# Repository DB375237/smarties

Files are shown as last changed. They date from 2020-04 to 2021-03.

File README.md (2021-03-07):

# Smarties™ Dispenser

Basic Arduino based dispenser. It can be activated via Bluetooth with an HC-05 module.

Dispenser in Action

## How it started
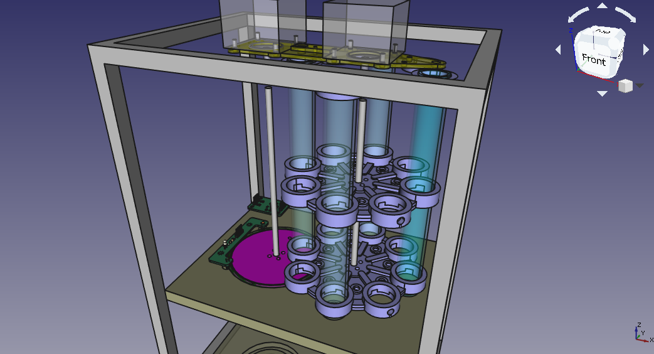
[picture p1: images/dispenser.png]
Rendering of Dispenser


## How it's going
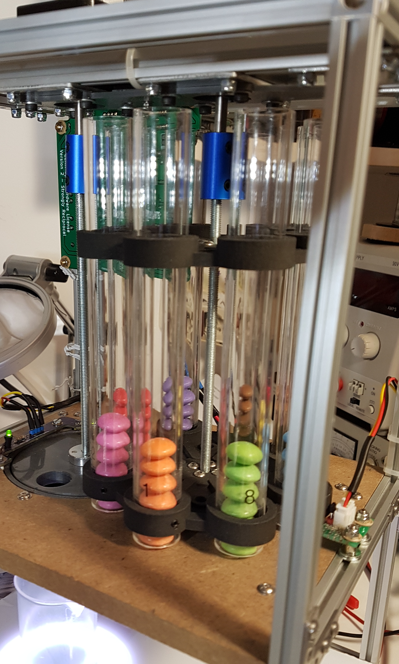
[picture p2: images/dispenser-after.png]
Actual Photo of Dispenser


## Warning
Some of the materials used in this project may not be food-safe. This is not meant to be an actual dispenser.

USE IT AT YOUR OWN RISK

## Licences

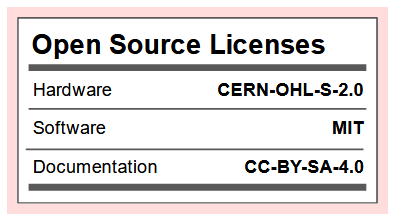
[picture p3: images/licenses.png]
Open Source Licenses "Facts"


(generated via https://oshwa.github.io/certification-mark-generator/facts)

## Note
Smarties™ is registered trademark of Nestlé

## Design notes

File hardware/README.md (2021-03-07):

# Smarties™ Dispenser - Hardware & Electronics

## Electronics
* [Mainboard with Arduino Nano 3.0](https://github.com/DB375237/smarties/blob/b078c1b0aad8f324e57391940284d2553f00b74f/images/power-board.png) ([schematic](https://github.com/DB375237/smarties/blob/d43ba06c84b01cdf67dcf4e3967283928ad1ec0a/hardware/power-board.pdf))
* [2003-hall-sensors-board-platter](https://github.com/DB375237/smarties/tree/master/hardware/2003-hall-sensors-board-platter)
* [2003-hall-sensors-board (comparators)](https://github.com/DB375237/smarties/tree/master/hardware/2003-hall-sensor)
* 1 x [24 RGB LEDs Ring (WS2812)](https://www.futurashop.it/RING24NEOPIXEL-ANELLO-24LED-NEOPIXEL)
* 2 x [NEMA 17 Stepper Motors](https://github.com/DB375237/smarties/blob/master/pdf/17HS13-0404S.pdf)
* 2 x [IR Break Beam Sensor - 5mm LEDs](https://www.adafruit.com/product/2168)
* 2 x [A4988 Stepper Motor Driver Carrier](https://www.amazon.it/gp/product/B071P41ZBW/)
* 2 x [KY-003 Hall Magnetic Sensor Module](https://www.amazon.it/gp/product/B07V3S94HZ)
* 1 x [Arduino Nano V3.0](https://www.amazon.it/AZDelivery-Nano-migliorata-compatibile-V3/dp/B0755XYBG4)

## Hardware
* [MakerBeam](https://www.makerbeam.com/makerbeam/) - assorted 10x10mm aluminum profiles & brackets
* [Pololu Universal Aluminum Mounting Hub for 5mm Shaft, M3 Holes](https://www.pololu.com/product/1998) ([pdf](https://github.com/DB375237/smarties/blob/master/pdf/1998-5mm-m3-hub-dimensions.pdf))
* [Plexiglass tubes - 20 mm outer diameter (16 mm inner diameter)](https://www.leroymerlin.it/catalogo/barra-tonda-in-pmma-trasparente-20-x-1000-mm--20-mm-35464205-p)
* 2 x [Miniature Ball Bearing MR115 2RS (5 x 11 x4 mm)](https://www.amazon.it/gp/product/B07CXN1143)
* 2 x [Stepper Motor Shaft Couplers (5 mm)](https://www.futurashop.it/giunto-in-alluminio-5-mm-5-mm-8300-hub5mm5)
* 2 x [Neodymium Disc Magnets (5 x 3 mm)](https://www.amazon.it/gp/product/B00389VRZW)
* 2 x [M5 Threaded Rod - 200 mm](https://www.leroymerlin.it/catalogo/barra-filettata-standers-in-acciaio--m5-l-20-mm-35736323-p)
* 10 mm MDF ([top](https://github.com/DB375237/smarties/blob/master/pdf/mdf-base.pdf), [bottom](https://github.com/DB375237/smarties/blob/master/pdf/mdf-base-02.pdf))

## 3D Printed Parts
* Carousel Axle Ball Bearing Holder ([stl](https://github.com/DB375237/smarties/blob/master/stl/bearing-holder-1-00-02-FINAL.stl), [img](https://github.com/DB375237/smarties/blob/master/images/bearing01.png))
* Rotating Platter Axle Ball Bearing Holder ([stl](https://github.com/DB375237/smarties/blob/master/stl/bearing-holder-platter-01-01-Final.stl), [img](https://github.com/DB375237/smarties/blob/master/images/bearing02.png))
* Rotating Platter ([stl](https://github.com/DB375237/smarties/blob/master/stl/platter-01-01-FINAL.stl), [img](https://github.com/DB375237/smarties/blob/master/images/platter.png))
* Rotating Platter Base ([stl](https://github.com/DB375237/smarties/blob/master/stl/base-piatto-01-01-FINAL.stl), [img](https://github.com/DB375237/smarties/blob/master/images/base_piatto.png))
* Carousel Tubes Holders ([stl](https://github.com/DB375237/smarties/blob/master/stl/carousel-plate-2-01-01-FINAL.stl), [img](https://github.com/DB375237/smarties/blob/master/images/carousel-ring.png))
* Stepper Motors Spacer ([stl](https://github.com/DB375237/smarties/blob/master/stl/step-motor-spacer-01-01-FINAL.stl), [front](https://github.com/DB375237/smarties/blob/master/images/stepper-spacer-01.png), [back](https://github.com/DB375237/smarties/blob/master/images/stepper-spacer-02.png), [pdf](https://github.com/DB375237/smarties/blob/master/pdf/stepper-spacer.pdf))
* Drop Sensor ([stl](https://github.com/DB375237/smarties/blob/master/stl/ir-barrier-01-01-FINAL.stl), [img](https://github.com/DB375237/smarties/blob/master/images/ir-barrier.png))
* RGB LEDs Ring Holder ([stl](https://github.com/DB375237/smarties/blob/master/stl/pixel-ring-01-FINAL.stl), [img](https://github.com/DB375237/smarties/blob/master/images/pixel-ring-holder.png))

## License

Copyright © 2020-2021 DB375237 (Dario B.)

The hardware part of the Smarties™ Dispenser project is licensed under the [CERN Open Hardware Licence Version 2 - Strongly Reciprocal](https://github.com/DB375237/smarties/blob/1d4773c20f6e62bb15a9346e1278c39deedc8825/LICENSE.hardware.md)

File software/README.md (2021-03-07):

# Smarties™ Dispenser

Basic firmware to test board.

# License

Copyright © 2020-2021 DB375237 (Dario B.)

The software part of the Smarties™ Dispenser project is licensed under the [MIT License](https://github.com/DB375237/smarties/blob/58d950f901a84a62662fe126237eb2720b643479/LICENSE.software.md)

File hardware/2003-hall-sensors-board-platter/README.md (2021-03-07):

# Hall Effect Sensors Board (rotating platter)

KiCad project of the board for the Hall effect sensors to control the positioning of the rotating platter.

It's based on the [KY-003 sensors](https://www.amazon.it/gp/product/B07V3S94HZ).

(prototype built uses only one sensor)

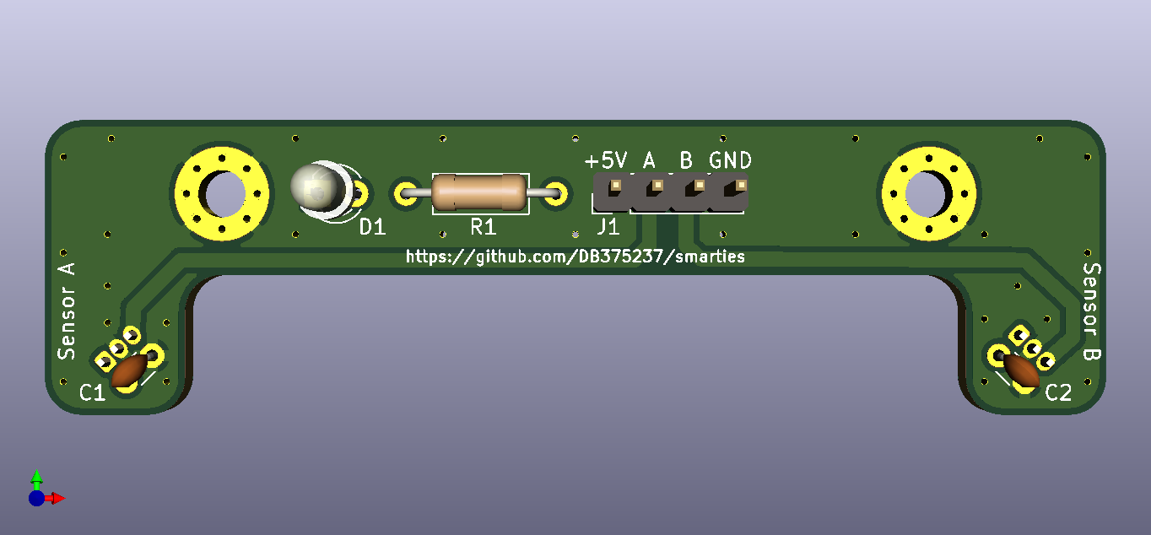
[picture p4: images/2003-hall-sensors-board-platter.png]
Hall Effect Sensors Board - rotating platter

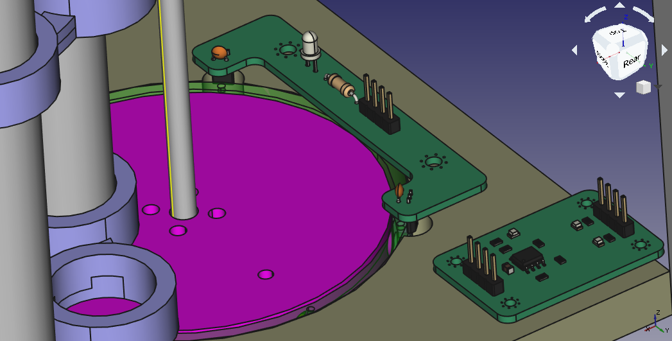
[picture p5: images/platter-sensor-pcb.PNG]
Hall Effect Sensors Board - rotating platter - mounting


## License

Copyright © 2020-2021 DB375237 (Dario B.)

The hardware part of the Smarties™ Dispenser project is licensed under the [CERN Open Hardware Licence Version 2 - Strongly Reciprocal](https://github.com/DB375237/smarties/blob/1d4773c20f6e62bb15a9346e1278c39deedc8825/LICENSE.hardware.md)

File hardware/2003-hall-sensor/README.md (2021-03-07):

# Hall Effect Sensors Board (comparators)

KiCad project of the board for the comparators for signal coming from Hall effect sensors.

It's based on the [LMV393](https://github.com/DB375237/smarties/blob/master/pdf/lmv393.pdf) low voltage comparator.

(required only for "analog" Hall sensors - not used in the prototype built - ** UNTESTED DESIGN **)

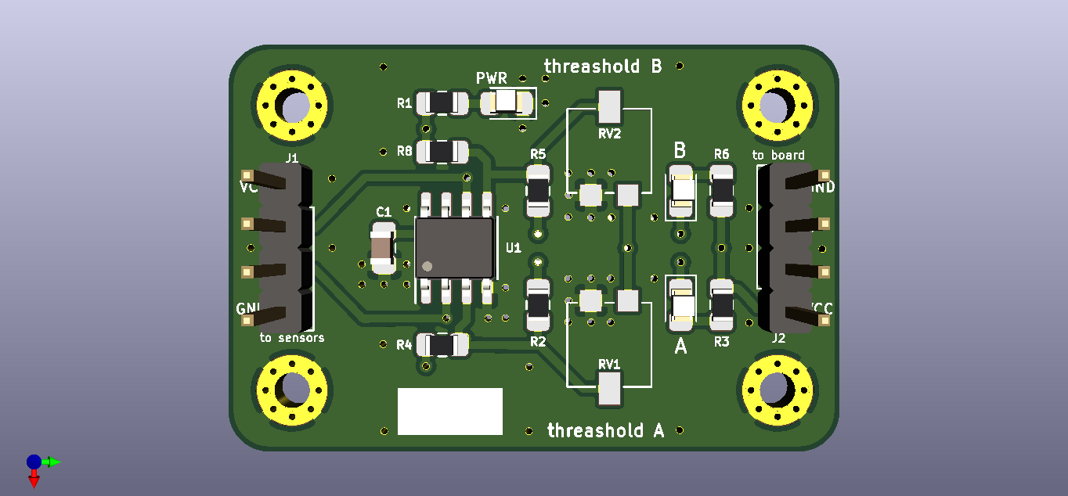
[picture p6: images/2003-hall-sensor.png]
Hall Effect Sensors Board (comparators)


## License

Copyright © 2020-2021 DB375237 (Dario B.)

The hardware part of the Smarties™ Dispenser project is licensed under the [CERN Open Hardware Licence Version 2 - Strongly Reciprocal](https://github.com/DB375237/smarties/blob/1d4773c20f6e62bb15a9346e1278c39deedc8825/LICENSE.hardware.md)

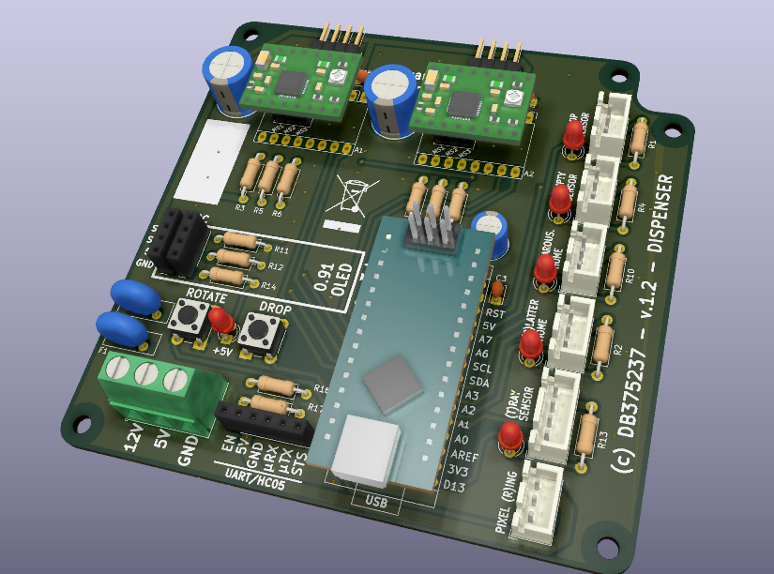
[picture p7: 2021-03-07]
images/power-board.png

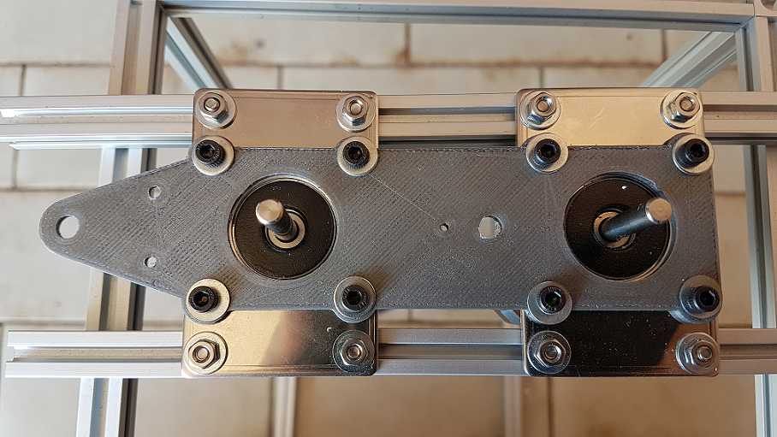
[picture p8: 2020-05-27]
images/stepper-spacer-01.png

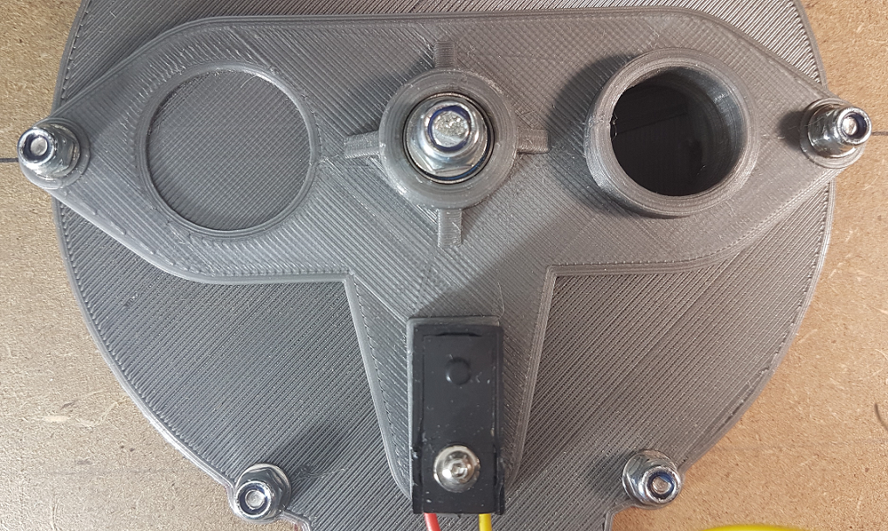
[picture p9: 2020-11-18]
images/bearing02.png

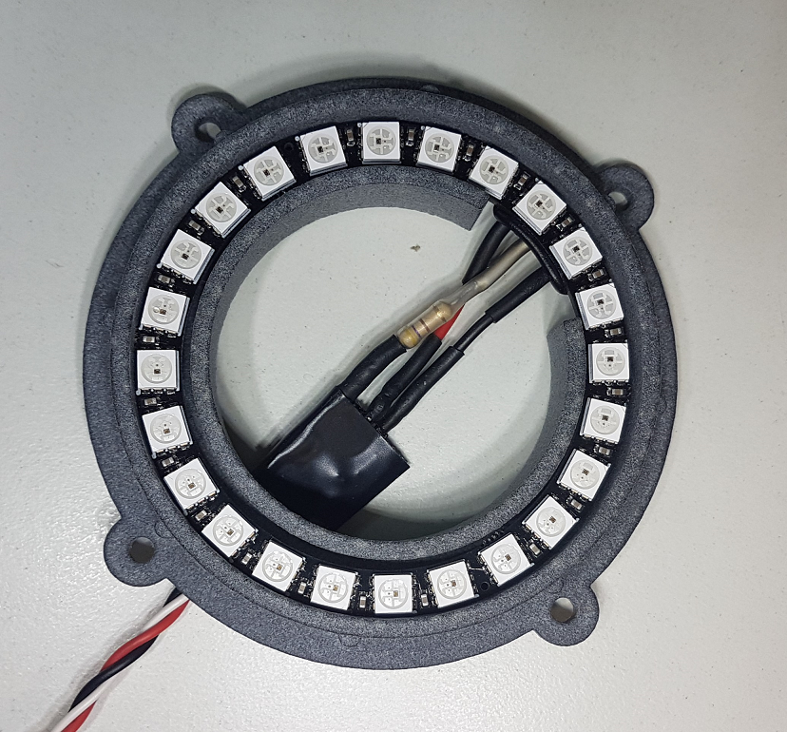
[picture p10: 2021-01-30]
images/pixel-ring-holder.png

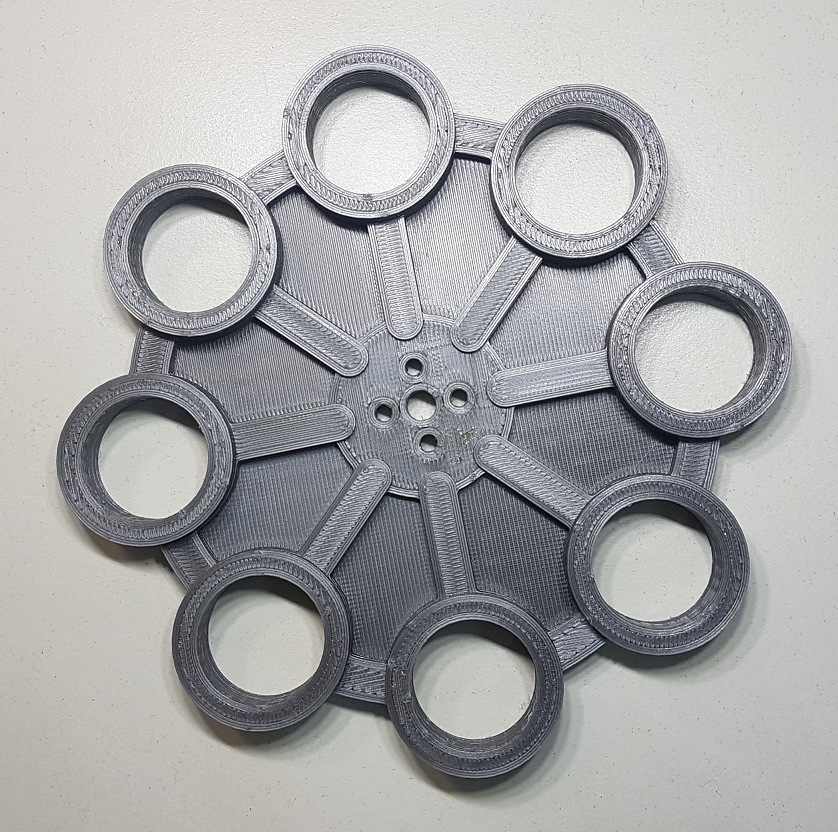
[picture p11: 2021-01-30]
images/carousel-ring.png

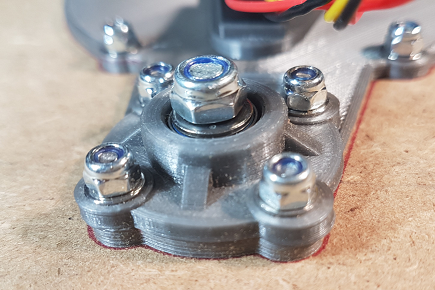
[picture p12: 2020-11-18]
images/bearing01.png

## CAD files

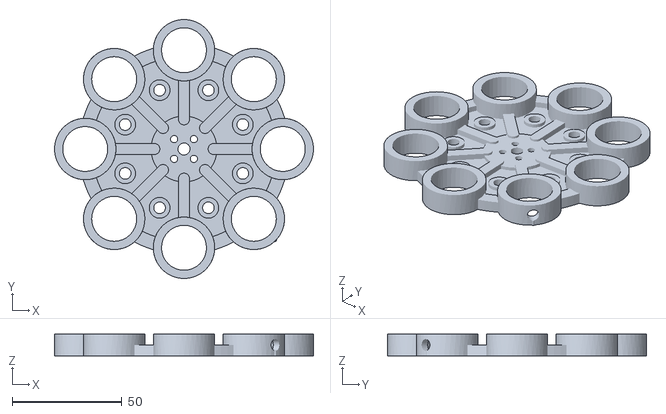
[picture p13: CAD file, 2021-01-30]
stl/carousel-plate-2-01-01-FINAL.stl
118.0 x 118.0 x 10.0

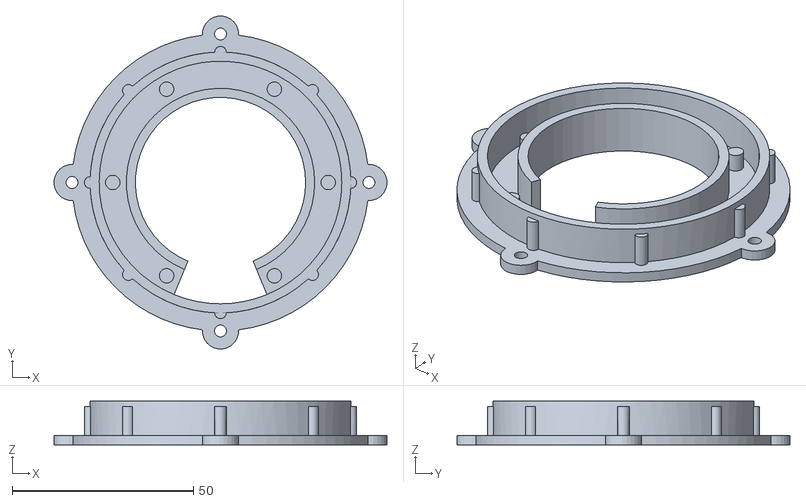
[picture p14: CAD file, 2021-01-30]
stl/pixel-ring-01-FINAL.stl
92.0 x 92.0 x 12.1

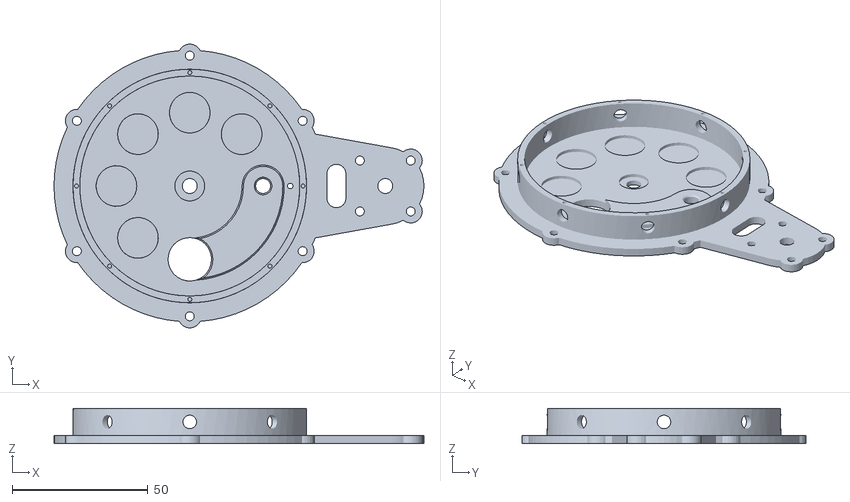
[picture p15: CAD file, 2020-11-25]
stl/base-piatto-01-01-FINAL.stl
136.2 x 104.4 x 13.0

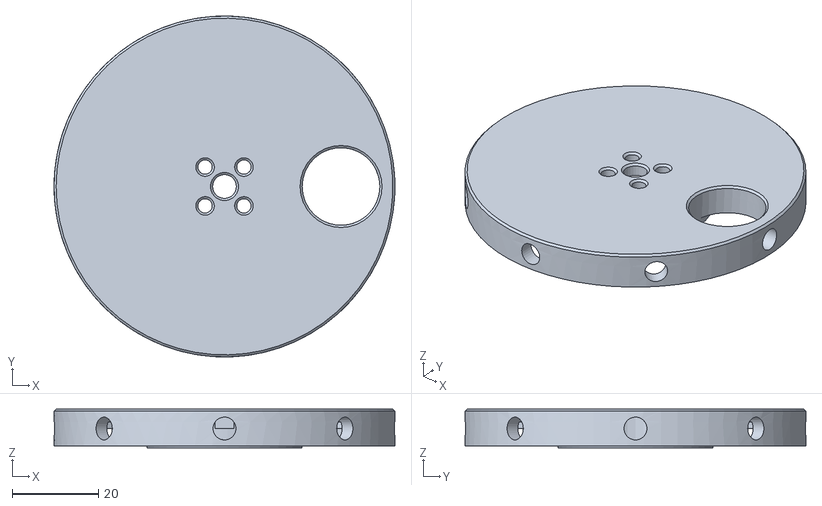
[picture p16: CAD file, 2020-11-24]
stl/platter-01-01-FINAL.stl
79.0 x 79.0 x 9.00

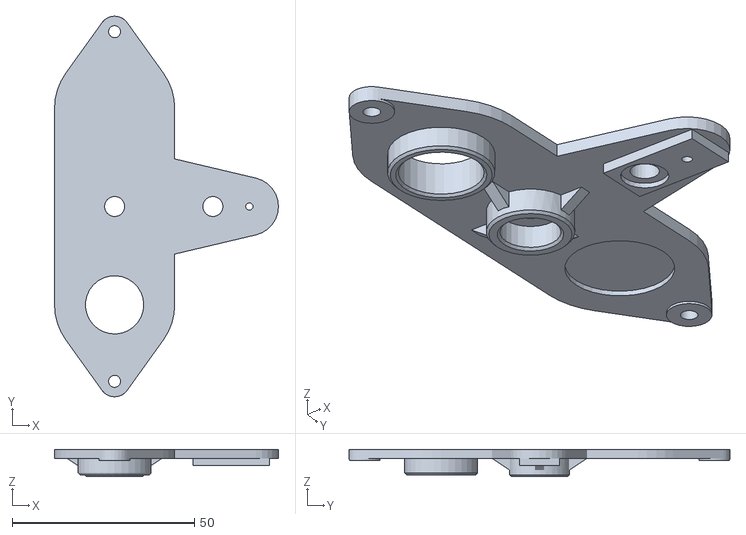
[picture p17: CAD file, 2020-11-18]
stl/bearing-holder-platter-01-01-Final.stl
61.5 x 104.5 x 7.50

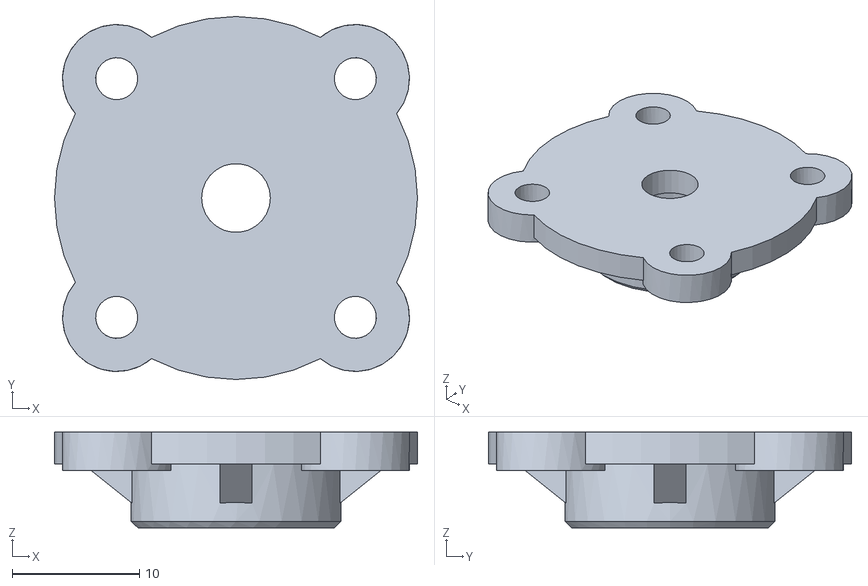
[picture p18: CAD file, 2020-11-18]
stl/bearing-holder-1-00-02-FINAL.stl
28.5 x 28.5 x 7.50

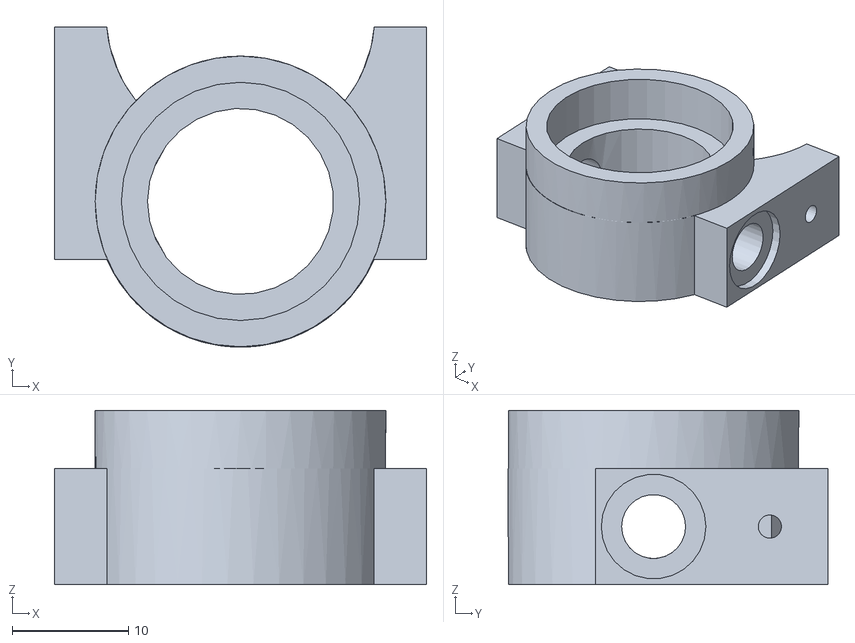
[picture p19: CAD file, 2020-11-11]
stl/ir-barrier-01-01-FINAL.stl
32.0 x 27.5 x 15.0

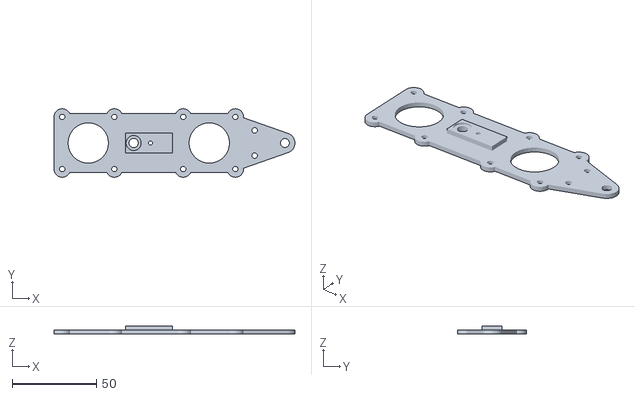
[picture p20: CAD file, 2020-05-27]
stl/step-motor-spacer-01-01-FINAL.stl
143.4 x 40.8 x 5.00

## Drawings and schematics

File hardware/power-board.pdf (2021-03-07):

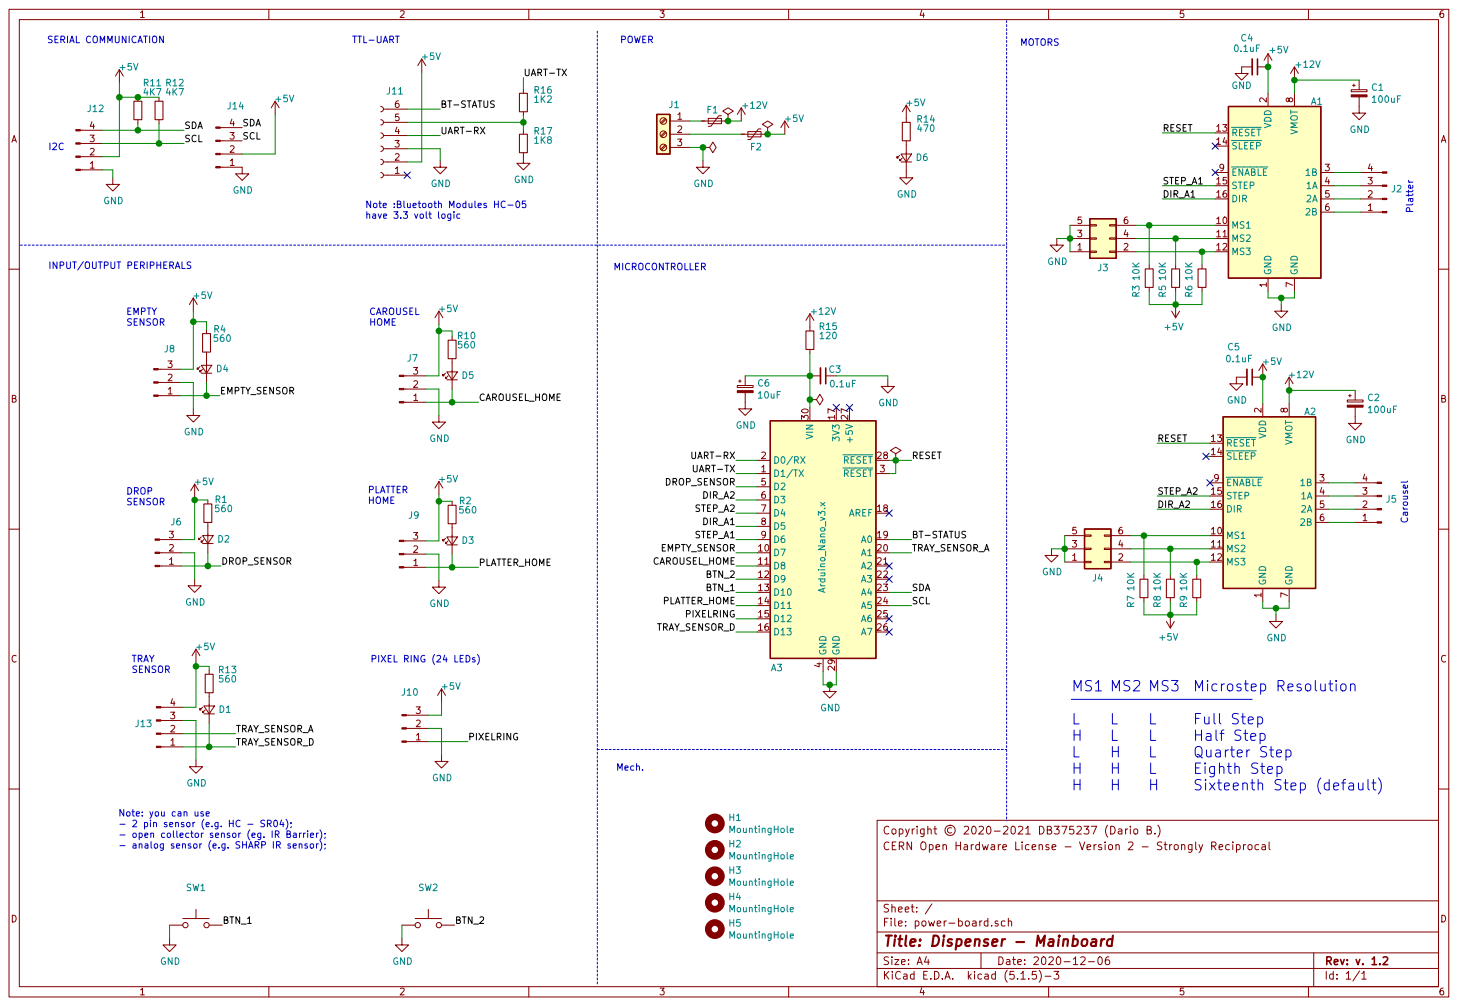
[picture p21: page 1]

1 MS1 10 MS2 11 MS3 12 RESET 13 SLEEP 14 STEP 15 DIR 16 VDD

Note :Bluetooth Modules HC-05

3 1 | 4

- 2 pin sensor (e.g. HC - SR04);
- open collector sensor (eg. IR Barrier);
- analog sensor (e.g. SHARP IR sensor);

File: power-board.sch Sheet: / CERN Open Hardware License - Version 2 - Strongly Reciprocal

Id: 1/1 Title: Dispenser - Mainboard

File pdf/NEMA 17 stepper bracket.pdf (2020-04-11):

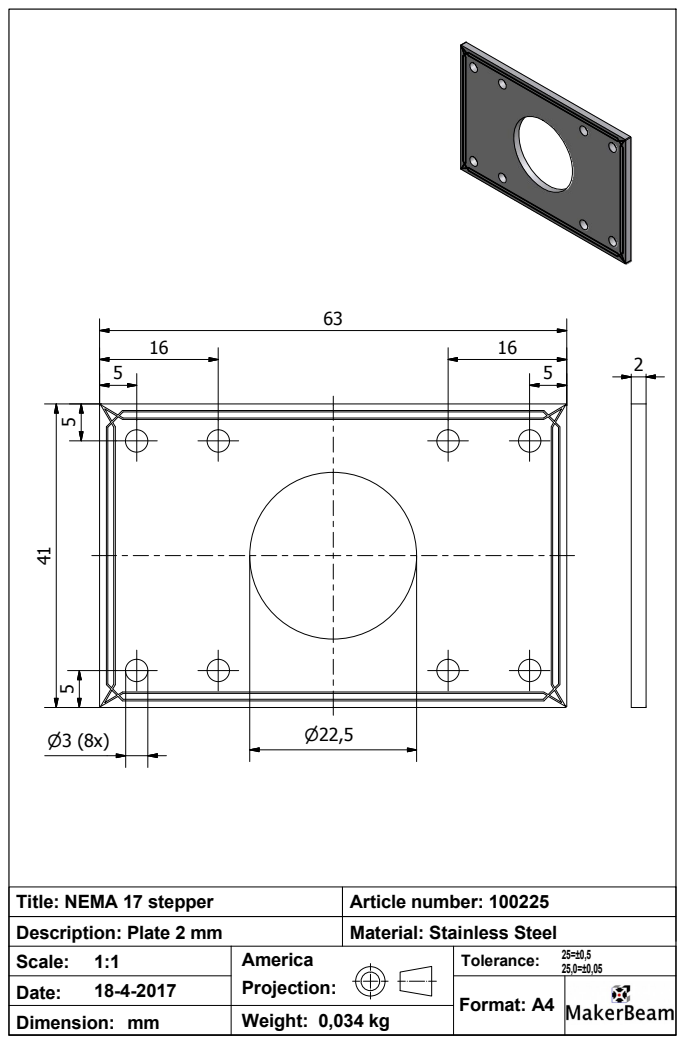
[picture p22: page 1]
America; Weight: 0,034 kg; 25=±0,5 Scale:; Date:; Dimension: mm; Format: A4; Tolerance:; Article number: 100225; Description: Plate 2 mm; Material: Stainless Steel; Projection:

Title: NEMA 17 stepper

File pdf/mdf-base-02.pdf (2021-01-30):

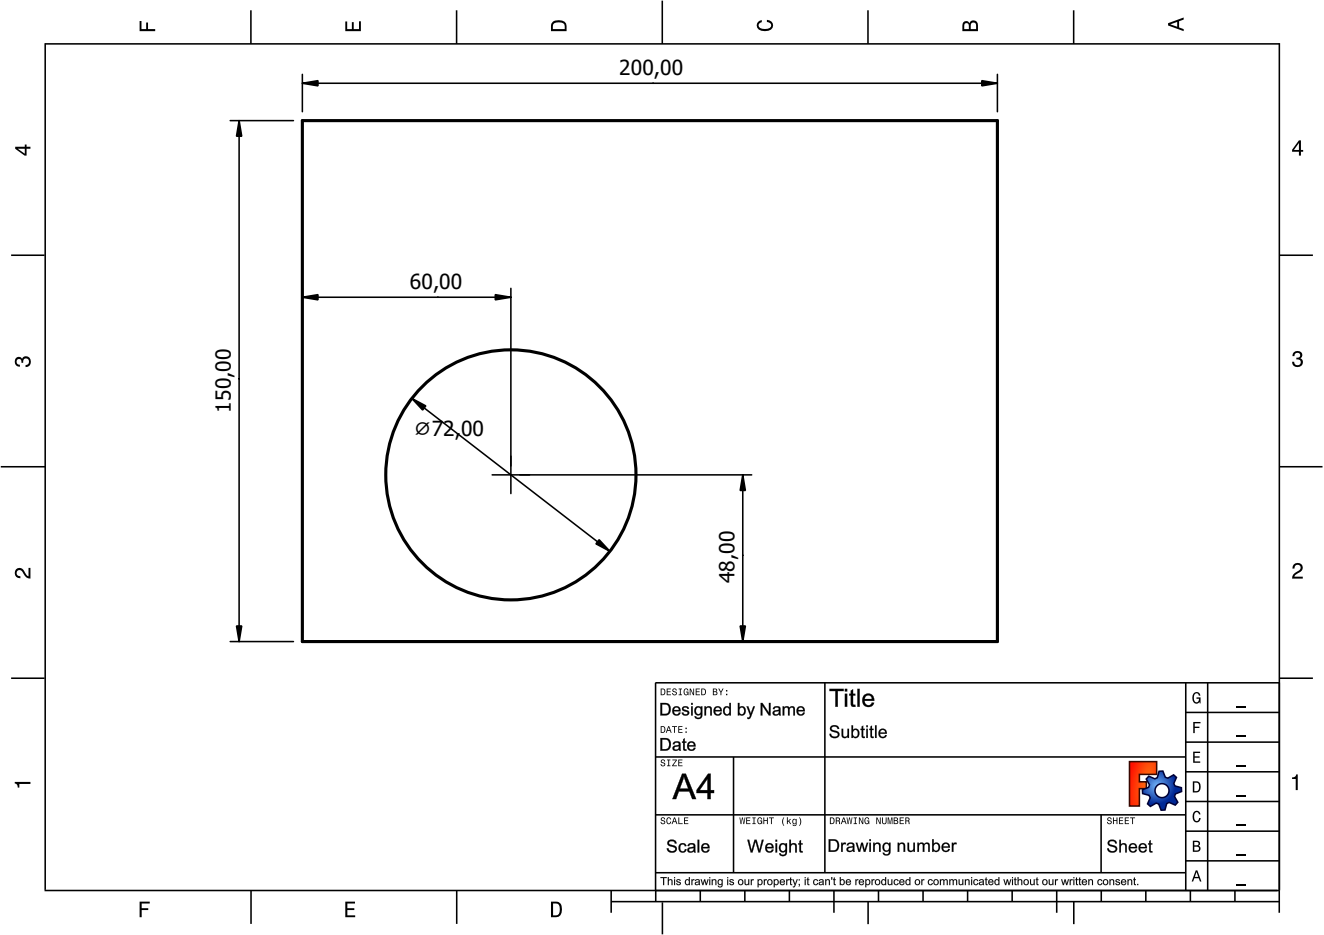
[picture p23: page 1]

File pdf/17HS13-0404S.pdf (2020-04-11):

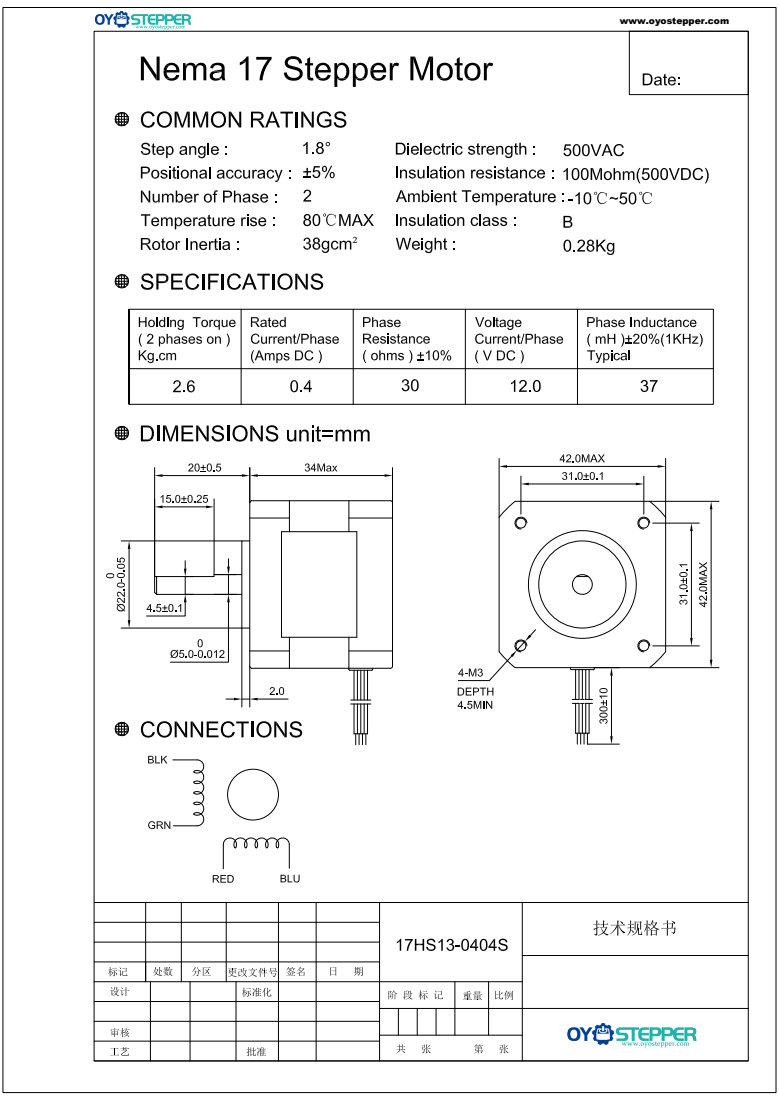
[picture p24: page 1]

www.oyostepper.com

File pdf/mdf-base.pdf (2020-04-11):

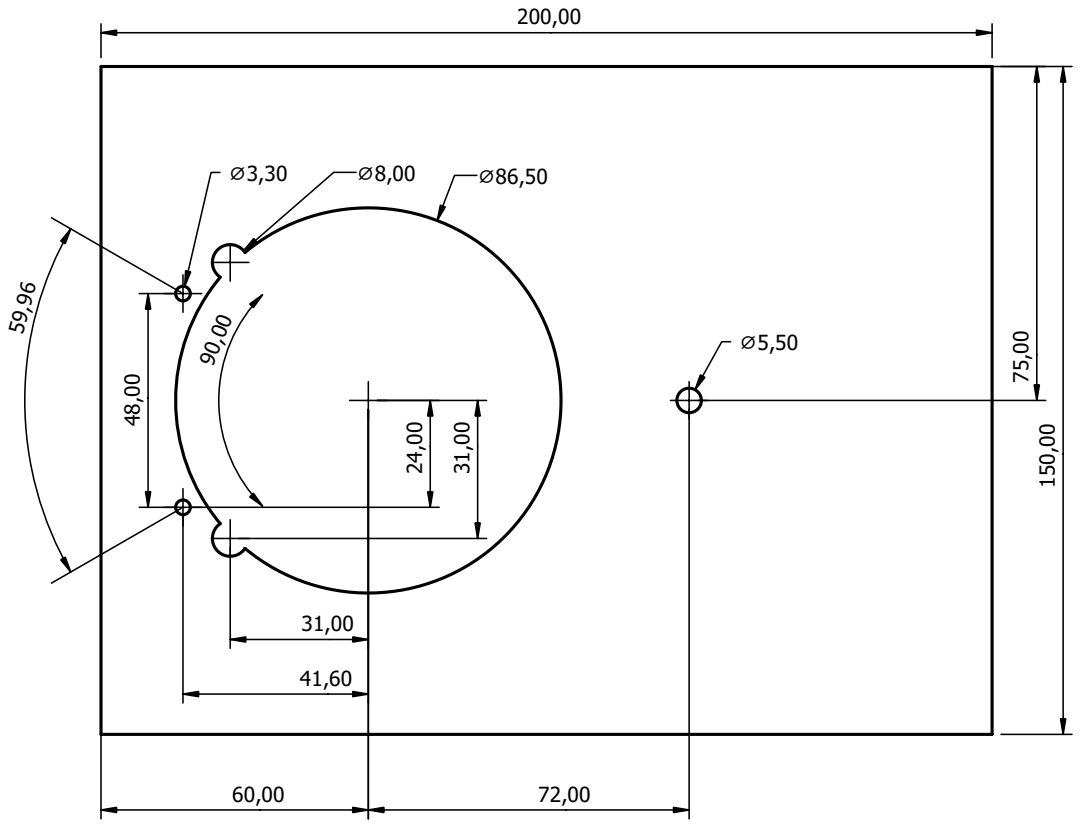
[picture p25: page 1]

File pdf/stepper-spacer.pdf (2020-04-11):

A

A

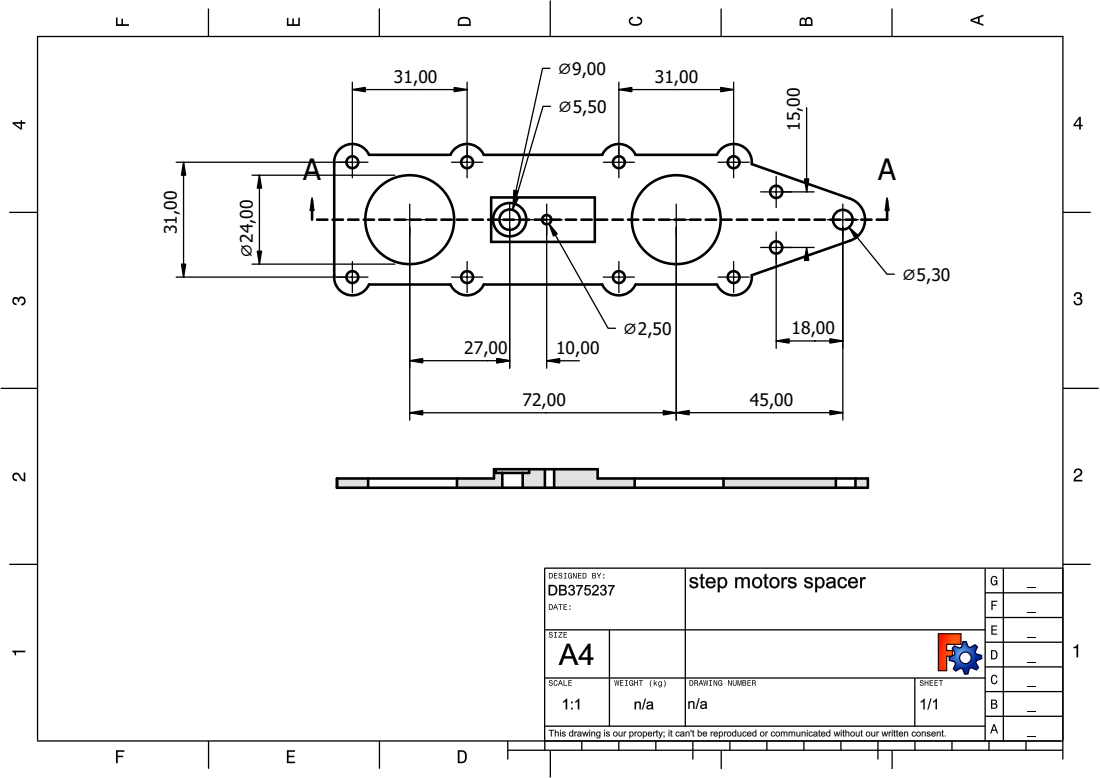
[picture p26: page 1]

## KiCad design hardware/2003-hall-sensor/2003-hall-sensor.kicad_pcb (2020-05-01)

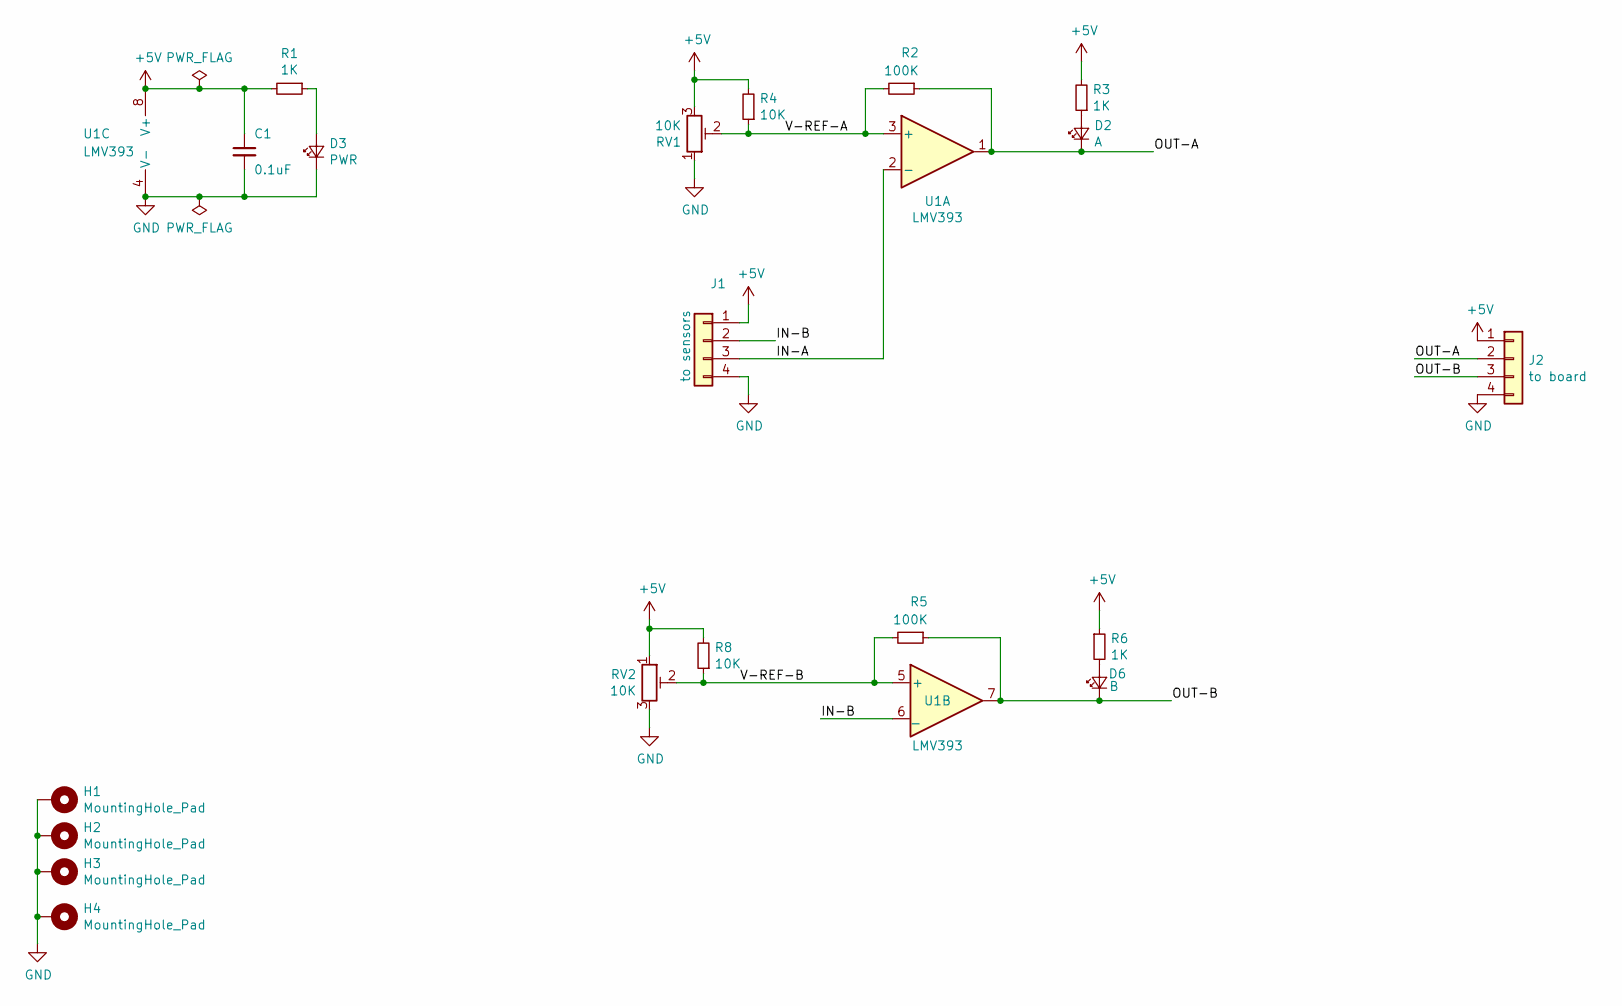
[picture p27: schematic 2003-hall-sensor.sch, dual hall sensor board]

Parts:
C1: 0.1uF; C_0805_2012Metric_Pad1.15x1.40mm_HandSolder
D2: A; LED_0805_2012Metric_Pad1.15x1.40mm_HandSolder
D3: PWR; LED_0805_2012Metric_Pad1.15x1.40mm_HandSolder
D6: B; LED_0805_2012Metric_Pad1.15x1.40mm_HandSolder
H1, H2, H3, H4: MountingHole_Pad; MountingHole_2.2mm_M2_Pad_Via
J1: to sensors; PinHeader_1x04_P2.54mm_Vertical
J2: to board; PinHeader_1x04_P2.54mm_Vertical
R1, R3, R6: 1K; R_0805_2012Metric_Pad1.15x1.40mm_HandSolder
R2, R5: 100K; R_0805_2012Metric_Pad1.15x1.40mm_HandSolder
R4, R8: 10K; R_0805_2012Metric_Pad1.15x1.40mm_HandSolder
RV1, RV2: 10K; Potentiometer_Vishay_TS53YL_Vertical
U1: LMV393

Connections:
+5V: C1.1, J1.1, J2.1, R1.2, R3.2, R4.2, R6.1, R8.2, RV1.3, RV2.1, U1.8 (V+)
/IN-A: J1.3, U1.2 (-)
/IN-B: J1.2, U1.6 (_)
/OUT-A: D2.1 (K), J2.2, R2.1, U1.1
/OUT-B: D6.1 (K), J2.3, R5.1, U1.7
/V-REF-A: R2.2, R4.1, RV1.2, U1.3 (+)
/V-REF-B: R5.2, R8.1, RV2.2, U1.5 (+)
GND: C1.2, D3.1 (K), H1.1, H2.1, H3.1, H4.1, J1.4, J2.4, RV1.1, RV2.3, U1.4 (V-)
unnamed: D2.2 (A), R3.1
unnamed: D3.2 (A), R1.1
unnamed: D6.2 (A), R6.2

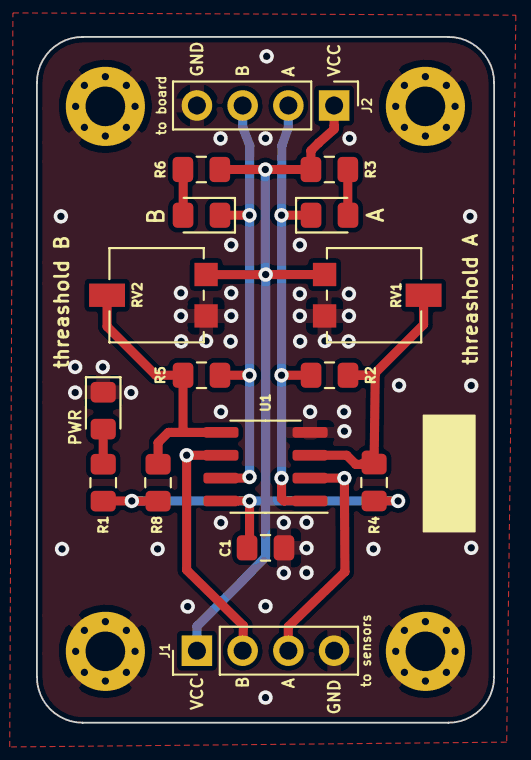
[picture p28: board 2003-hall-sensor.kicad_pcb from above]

Board: 2 copper layers, 25.4 x 38.1 mm, 20 parts (0 on the bottom side), 11 nets.

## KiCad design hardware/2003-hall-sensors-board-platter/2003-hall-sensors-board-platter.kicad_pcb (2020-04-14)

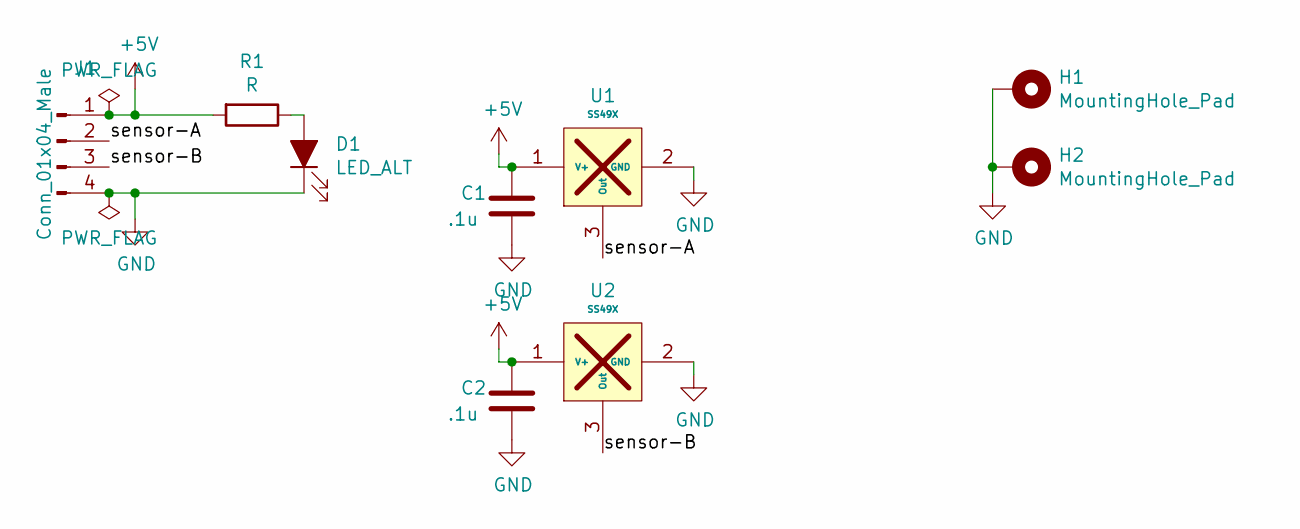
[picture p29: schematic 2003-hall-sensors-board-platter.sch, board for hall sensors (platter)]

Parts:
C1, C2: .1u; C_Disc_D3.0mm_W1.6mm_P2.50mm
D1: LED_ALT; LED_D3.0mm_Clear
H1, H2: MountingHole_Pad; MountingHole_3.2mm_M3_Pad_Via
J1: Conn_01x04_Male; PinHeader_1x04_P2.54mm_Vertical
R1: R; R_Axial_DIN0207_L6.3mm_D2.5mm_P10.16mm_Horizontal
U1, U2: SS49X; TO-92Flat

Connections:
+5V: C1.1, C2.1, J1.1, R1.2, U1.1 (V+), U2.1 (V+)
/sensor-A: J1.2, U1.3 (Out)
/sensor-B: J1.3, U2.3 (Out)
GND: C1.2, C2.2, D1.1 (K), H1.1, H2.1, J1.4, U1.2 (GND), U2.2 (GND)
unnamed: D1.2 (A), R1.1

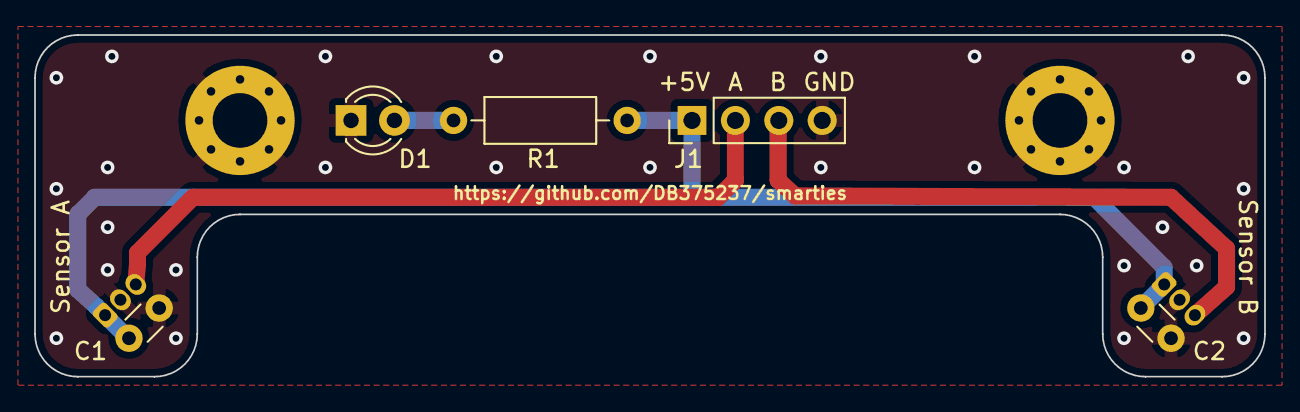
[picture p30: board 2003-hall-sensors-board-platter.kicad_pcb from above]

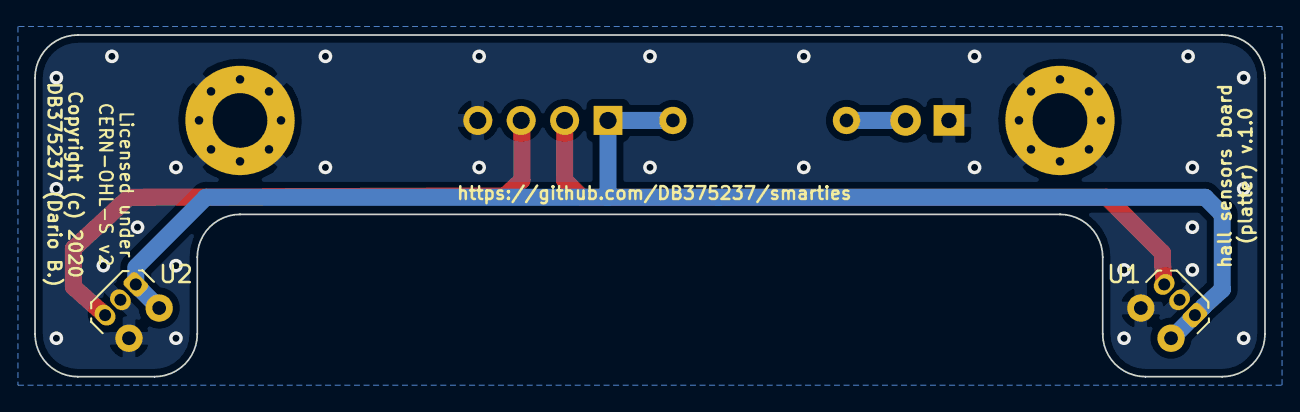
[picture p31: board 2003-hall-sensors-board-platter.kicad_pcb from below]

Board: 2 copper layers, 72.0 x 20.0 mm, 9 parts (2 on the bottom side), 5 nets.

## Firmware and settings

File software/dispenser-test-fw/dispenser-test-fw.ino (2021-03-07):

/*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
* The above copyright notice and this permission notice shall be included in all copies or substantial portions of the Software.
* THE SOFTWARE IS PROVIDED "AS IS", WITHOUT WARRANTY OF ANY KIND, EXPRESS OR IMPLIED, INCLUDING BUT NOT LIMITED TO THE WARRANTIES OF MERCHANTABILITY,
* FITNESS FOR A PARTICULAR PURPOSE AND NONINFRINGEMENT. IN NO EVENT SHALL THE AUTHORS OR COPYRIGHT HOLDERS BE LIABLE FOR ANY CLAIM,
* DAMAGES OR OTHER LIABILITY, WHETHER IN AN ACTION OF CONTRACT, TORT OR OTHERWISE, ARISING FROM,
* OUT OF OR IN CONNECTION WITH THE SOFTWARE OR THE USE OR OTHER DEALINGS IN THE SOFTWARE.
*/

#define DEBUG

#ifdef DEBUG
#define DEBUG_PRINT(x)    Serial.print(x)
#define DEBUG_PRINTHEX(x) Serial.print(x, HEX);
#define DEBUG_PRINTLN(x)  Serial.println(x)
#else
#define DEBUG_PRINT(x)
#define DEBUG_PRINTHEX(x)
#define DEBUG_PRINTLN(x)
#endif

#include <Wire.h>
#include <Adafruit_GFX.h>
#include <Adafruit_SSD1306.h>
#include <Adafruit_NeoPixel.h>
#include "dwStepperDriver.h"

#define SCREEN_WIDTH 128 // OLED display width, in pixels
#define SCREEN_HEIGHT 32 // OLED display height, in pixels
#define OLED_RESET     4 // Reset pin # (or -1 if sharing Arduino reset pin)
#define SCREEN_ADDRESS 0x3C //< See datasheet for Address; 0x3D for 128x64, 0x3C for 128x32

#define NUMPIXELS         24
#define DEFAULT_INTENSITY 64 //8 = 30mA, 16 = 40mA, 32 = 60mA, 64 = 80mA, 128 = 160mA (1 colore)

#define STEP_NUM          200

#define DROP_SENSOR_PIN   2 //OK
#define CAROUSEL_DIR_PIN  3
#define CAROUSEL_STEP_PIN 4
#define PLATTER_DIR_PIN   5 //OK
#define PLATTER_STEP_PIN  6 //OK
#define EMPTY_SENSOR_PIN  7 //OK
#define CAROUSEL_HOME_PIN 8 //OK
#define DROP_BTN_PIN      9 //OK
#define ROTATE_BTN_PIN    10 //OK
#define PLATTER_HOME_PIN  11 //OK
#define PIXEL_RING_PIN    12 //OK
#define TRAY_SENSOR_D_PIN 13 //OK

#define BT_STATUS_PIN     A0 //OK
#define TRAY_SENSOR_A_PIN A1 //OK

char str_buffer[100];

Adafruit_NeoPixel pixels(NUMPIXELS, PIXEL_RING_PIN, NEO_GRB + NEO_KHZ800);
Adafruit_SSD1306 display(SCREEN_WIDTH, SCREEN_HEIGHT, &Wire, OLED_RESET);
dwStepperDriver platterStepper(STEP_NUM, dwStepperDriver::SIXTEENTH_STEP, PLATTER_DIR_PIN, PLATTER_STEP_PIN, PLATTER_HOME_PIN);
dwStepperDriver carouselStepper(STEP_NUM, dwStepperDriver::SIXTEENTH_STEP, CAROUSEL_DIR_PIN, CAROUSEL_STEP_PIN, CAROUSEL_HOME_PIN);

volatile int counter = 0;
bool isTubeEmpty;

const unsigned char myBitmap [] PROGMEM = {
  0x00, 0x00, 0x00, 0x00, 0x00, 0x00, 0x00, 0x00, 0x00, 0x00, 0x00, 0x78, 0x00, 0x00, 0x00, 0x00, 
  0x00, 0x1f, 0xe0, 0x00, 0x00, 0x00, 0x00, 0x00, 0x00, 0x00, 0x00, 0xfc, 0x00, 0x00, 0x00, 0x00, 
  0x00, 0x3f, 0xf0, 0x00, 0x00, 0x00, 0x00, 0x00, 0x3c, 0x00, 0x01, 0xfc, 0x00, 0x00, 0x1f, 0xc0, 
  0x00, 0x7f, 0xf8, 0x00, 0x00, 0x00, 0x00, 0x0e, 0x7e, 0x00, 0x01, 0xfc, 0x00, 0x00, 0x7f, 0xe0, 
  0x00, 0xff, 0xf8, 0x00, 0x00, 0x00, 0x00, 0x1f, 0xfe, 0x00, 0x03, 0xfc, 0x3f, 0xc1, 0xff, 0xf0, 
  0x00, 0xff, 0xf8, 0xf4, 0x00, 0x00, 0x00, 0x3f, 0xfe, 0x07, 0xe3, 0xf8, 0xff, 0xe3, 0xff, 0xf8, 
  0x00, 0xff, 0xf9, 0xfc, 0x07, 0x80, 0x00, 0x7f, 0xfe, 0x3f, 0xf3, 0xf9, 0xff, 0xe3, 0xff, 0xf8, 
  0x01, 0xff, 0xfb, 0xff, 0x3f, 0xe0, 0x00, 0x7f, 0xfc, 0xff, 0xfb, 0xf1, 0xff, 0xe7, 0xff, 0xf0, 
  0x01, 0xff, 0x73, 0xff, 0xff, 0xe0, 0x70, 0x7f, 0xe1, 0xff, 0xfb, 0xf3, 0xff, 0xef, 0xff, 0xf0, 
  0x01, 0xfe, 0x03, 0xff, 0xff, 0xf0, 0xf8, 0x7f, 0xc3, 0xff, 0xf1, 0xc3, 0xff, 0xef, 0xff, 0xf0, 
  0x01, 0xfe, 0x07, 0xff, 0xff, 0xf0, 0xfc, 0x7f, 0xc7, 0xff, 0xc0, 0x07, 0xe3, 0xcf, 0xff, 0xe0, 
  0x00, 0xfe, 0x07, 0xff, 0xf7, 0xf1, 0xfe, 0x7f, 0xc7, 0xfe, 0x03, 0x87, 0xe0, 0x0f, 0xfc, 0x00, 
  0x00, 0xff, 0x07, 0xf3, 0xf3, 0xf1, 0xfe, 0x3f, 0xc7, 0x3e, 0x1f, 0xc7, 0xe0, 0x0f, 0xf8, 0x00, 
  0x00, 0xff, 0x07, 0xf1, 0xe3, 0xf3, 0xff, 0x3f, 0xe6, 0x3f, 0x1f, 0xe7, 0xfc, 0x0f, 0xf8, 0x00, 
  0x00, 0x7f, 0x87, 0xf1, 0xe3, 0xf3, 0xff, 0x3f, 0xe2, 0x3f, 0x1f, 0xe7, 0xff, 0x0f, 0xfc, 0x00, 
  0x00, 0x7f, 0xc7, 0xf1, 0xe3, 0xf7, 0xcf, 0x3f, 0xf0, 0x3f, 0x1f, 0xef, 0xff, 0x07, 0xfc, 0x00, 
  0x00, 0x3f, 0xc7, 0xf3, 0xe3, 0xe7, 0xcf, 0xbf, 0xf0, 0x3f, 0x9f, 0xef, 0xff, 0x07, 0xfc, 0x00, 
  0x00, 0x3f, 0xe7, 0xf3, 0xe7, 0xe7, 0xcf, 0x9f, 0xf8, 0x3f, 0x9f, 0xef, 0xff, 0x03, 0xfe, 0x00, 
  0x00, 0x3f, 0xe7, 0xf3, 0xe7, 0xe7, 0xff, 0xdf, 0xf8, 0x3f, 0x9f, 0xcf, 0xff, 0x03, 0xfe, 0x00, 
  0x00, 0x1f, 0xf7, 0xfb, 0xe7, 0xef, 0xff, 0xdf, 0xf8, 0x3f, 0xdf, 0xcf, 0xfe, 0x01, 0xff, 0x00, 
  0x00, 0x1f, 0xf7, 0xfb, 0xef, 0xef, 0xff, 0xcf, 0xf8, 0x3f, 0xdf, 0xcf, 0xe0, 0x00, 0xff, 0x00, 
  0x07, 0x9f, 0xf3, 0xfb, 0xef, 0xef, 0xff, 0xef, 0xf8, 0x3f, 0xdf, 0xcf, 0xe0, 0xc0, 0x7f, 0x80, 
  0x07, 0x3f, 0xf3, 0xfb, 0xef, 0xcf, 0xcf, 0xe7, 0xf0, 0x3f, 0xdf, 0xcf, 0xff, 0xe0, 0x3f, 0x80, 
  0x0f, 0xff, 0xf3, 0xf3, 0xef, 0xcf, 0xcf, 0xe7, 0xe0, 0x3f, 0xdf, 0xcf, 0xff, 0xe0, 0x3f, 0x80, 
  0x0f, 0xff, 0xf1, 0xf1, 0xcf, 0xcf, 0xcf, 0xe1, 0x80, 0x3f, 0xcf, 0x8f, 0xff, 0xf0, 0xff, 0x80, 
  0x1f, 0xff, 0xf1, 0xf0, 0x07, 0x8f, 0xcf, 0xe0, 0x00, 0x3f, 0x8f, 0x8f, 0xff, 0xf7, 0xff, 0x80, 
  0x1f, 0xff, 0xe0, 0x00, 0x07, 0x07, 0xcf, 0xc0, 0x00, 0x1f, 0x0f, 0x87, 0xff, 0xe7, 0xff, 0x80, 
  0x0f, 0xff, 0xe0, 0x00, 0x00, 0x03, 0x03, 0x80, 0x00, 0x04, 0x0f, 0x87, 0xff, 0xe7, 0xff, 0x80, 
  0x0f, 0xff, 0xc0, 0x00, 0x00, 0x00, 0x00, 0x00, 0x00, 0x00, 0x07, 0x83, 0xff, 0xe7, 0xff, 0x00, 
  0x07, 0xff, 0x80, 0x00, 0x00, 0x00, 0x00, 0x00, 0x00, 0x00, 0x07, 0x01, 0xff, 0xc7, 0xff, 0x00, 
  0x03, 0xff, 0x00, 0x00, 0x00, 0x00, 0x00, 0x00, 0x00, 0x00, 0x00, 0x00, 0x7f, 0x03, 0xfc, 0x00, 
  0x00, 0xfc, 0x00, 0x00, 0x00, 0x00, 0x00, 0x00, 0x00, 0x00, 0x00, 0x00, 0x00, 0x00, 0x00, 0x00

};

void setup() {
  // put your setup code here, to run once:
  pinMode(DROP_SENSOR_PIN, INPUT);
  pinMode(EMPTY_SENSOR_PIN, INPUT); 
  pinMode(TRAY_SENSOR_D_PIN, OUTPUT);
  pinMode(PIXEL_RING_PIN, OUTPUT); 
  pinMode(TRAY_SENSOR_A_PIN, INPUT);      
  pinMode(BT_STATUS_PIN, INPUT);      
  pinMode(DROP_BTN_PIN, INPUT_PULLUP);
  pinMode(ROTATE_BTN_PIN, INPUT_PULLUP);

  attachInterrupt(digitalPinToInterrupt(DROP_SENSOR_PIN), pin_ISR_CHANGE, CHANGE);  
  
  // initialize serial:
  Serial.begin(9600);

  // SSD1306_SWITCHCAPVCC = generate display voltage from 3.3V internally
  if(!display.begin(SSD1306_SWITCHCAPVCC, SCREEN_ADDRESS)) {
    Serial.println(F("SSD1306 allocation failed"));
    for(;;); // Don't proceed, loop forever
  }

  drawLogo();
  
  pixels.begin(); // INITIALIZE NeoPixel strip object (REQUIRED)
  pixels.clear(); // Set all pixel colors to 'off'
  pixels.show();   // Send the updated pixel colors to the hardware.

  setRingColor(DEFAULT_INTENSITY, 0, 0);
  delay(1000);  

  setRingColor(0, DEFAULT_INTENSITY, 0);
  delay(1000);  

  setRingColor(0, 0, DEFAULT_INTENSITY);
  delay(1000);  

  setRingColor(DEFAULT_INTENSITY, DEFAULT_INTENSITY, DEFAULT_INTENSITY);
  delay(1000);  

  platterStepper.setRPM(20);
  if(platterStepper.home()) {
    DEBUG_PRINTLN("HOMED 1");    
  }
  delay(1000);

  carouselStepper.setRPM(20);
  if(carouselStepper.home()) {
    DEBUG_PRINTLN("HOMED 2");    
  }

  delay(1000);
}

void pin_ISR_CHANGE() {
  counter++;
}

void drawLogo(void) {
  display.clearDisplay();

  display.drawBitmap(0, 0, myBitmap, SCREEN_WIDTH, SCREEN_HEIGHT, WHITE);
  
  display.display();
  delay(1000);
}

void loop() { 
  if(LOW == digitalRead(ROTATE_BTN_PIN)){
    carouselStepper.rotate(125);
    //delay(1000);
  }    

  if(LOW == digitalRead(DROP_BTN_PIN)){
    counter = 0;
    platterStepper.rotate(250);
    delay(500);
    isTubeEmpty = (HIGH == digitalRead(EMPTY_SENSOR_PIN));    
    DEBUG_PRINTLN(isTubeEmpty ? "Empty": "Qty OK");
    if(isTubeEmpty){
      setRingColor(DEFAULT_INTENSITY, 0, 0);
    }else{
      setRingColor(0, DEFAULT_INTENSITY, 0);      
    }
    delay(500);
    platterStepper.rotate(-250);
    delay(500);
    if(2 == counter){
      DEBUG_PRINTLN("Dropped");      
      setRingColor(0, DEFAULT_INTENSITY, 0);
    }else if(!isTubeEmpty){
      DEBUG_PRINTLN("Stuck");            
      setRingColor(DEFAULT_INTENSITY, 0, 0);
    }
    delay(500);   
    setRingColor(DEFAULT_INTENSITY, DEFAULT_INTENSITY, DEFAULT_INTENSITY);    
  }
}

/***************************************************************
   setRingColor()
 ***************************************************************/
void setRingColor(uint8_t r, uint8_t g, uint8_t b) {
  pixels.clear(); // Set all pixel colors to 'off'
  for (int i = 0; i < NUMPIXELS; i++) { // For each pixel...
    // pixels.Color() takes RGB values, from 0,0,0 up to 255,255,255
    pixels.setPixelColor(i, pixels.Color(r, g, b));
  }
  pixels.show();   // Send the updated pixel colors to the hardware.
}

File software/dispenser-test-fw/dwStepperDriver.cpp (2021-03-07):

/*
 * dwStepperDriver.h - Stepper library for Arduino
 *
 * Based on Arduino Stepper Library
 *
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
 *
 * Drives a bipolar stepper motor.
 *
 *
 */

#include "Arduino.h"
#include "dwStepperDriver.h"

#define PULSE_WIDTH 5
#define DELAY_MILLI 100

/*
 * constructor.
 *
 * number_of_steps: full steps per revolution of the motor shaft
 * microstep_size:  microstepping size (i.e. number of microsteps for each full step
 * dir_pin:         pin connected to DIR signal
 * step_pin:        pin connected to STEP signal
 * home_pin:        pin connected to sensor used for homing.
 * 
 * Note:
 *  a. the code assumes sensor reads LOW in home position (e.g an open collector sensor);
 *  b. uint16_t _number_of_microsteps assumes (this->_number_of_steps) < 65K
 */
dwStepperDriver::dwStepperDriver(uint16_t number_of_steps, StepSize microstep_size, uint8_t dir_pin, uint8_t step_pin, uint8_t home_pin)
{
  this->_microstep_size = microstep_size;
  this->_number_of_microsteps = (number_of_steps * this->_microstep_size); // total number of microsteps for this motor

  // Arduino pins for the motor control connection:
  this->_dir_pin = dir_pin;
  this->_step_pin = step_pin;
  this->_home_pin = home_pin;
  
  // setup the pins on the microcontroller:
  pinMode(this->_dir_pin, OUTPUT);
  pinMode(this->_step_pin, OUTPUT);
  pinMode(this->_home_pin, INPUT_PULLUP);
  //
  this->setRPM(1);
}

/**************************************************************
 * Sets the speed in Revs Per Minute (RPM)
 **************************************************************/
void dwStepperDriver::setRPM(uint16_t rpm)
{
  //compute delay in microseconds
  this->_step_delay = (60L * 1000L * 1000L) / (this->_number_of_microsteps * rpm);
}

/**************************************************************
 * Moves the motor steps_to_move steps.  If the number is negative,
 * the motor moves in the reverse direction.
 **************************************************************/
void dwStepperDriver::step(int16_t number_of_steps)
{
  uint16_t steps = abs(number_of_steps);  // how many steps to take
  
  // determine direction based on whether steps_to_mode is + or -:
  digitalWrite(this->_dir_pin, number_of_steps >= 0 ? HIGH : LOW );
  
  for(uint16_t i = 0L; i < steps; i++){
    this->stepMotor();
    delayMicroseconds(this->_step_delay);
  }
}

/**************************************************************
 * Move the motor to home position
 **************************************************************/
bool dwStepperDriver::home()
{
  uint8_t val_Home, previous_val_Home;
  uint16_t step1, step2, backtrack;
  uint16_t steps;

  //leave area near home...
  steps = 0;
  while ((steps < this->_number_of_microsteps) && (LOW == digitalRead(this->_home_pin))) {
    this->step(-1);
    steps++;
  }

  //if sensor reads LOW for an entire revolution, something must be wrong
  if(steps == this->_number_of_microsteps) return false;

  //at the end of previous while loop, home sensor must read HIGH
  delay(DELAY_MILLI);
  previous_val_Home = HIGH;
  step1 = step2 = 0;
  //bounds included to make sure we've returned to original position
  for (uint16_t i = 0; i <= this->_number_of_microsteps; i++) {
    val_Home = digitalRead(this->_home_pin);
   
    if (val_Home != previous_val_Home) {        
      //sensor read changed
      previous_val_Home = val_Home;
      if (LOW == val_Home) {
        step1 = i;
      } else {
        //i.e. HIGH == val_Home
        step2 = i;
        break;
      }
    }
    
    this->step(1);  
  }
  //if at least one of the positions was not identified, something must be wrong
  if((0 == step1) || (0 == step2)) return false;

  //number of steps to backtrack
  delay(DELAY_MILLI);
  backtrack = (step2 - step1) >> 1;
  for (uint16_t i = 0; i <= backtrack; i++) {
    this->step(-1);  
  }  
  
  return true;
}

/**************************************************************
 * rotate thousands_of_turn e.g. 500 = 0.5 turn = 180° 
 * If the number is negative, the motor moves in the reverse direction.
 **************************************************************/
void dwStepperDriver::rotate(int16_t thousands_of_turn){
  int32_t steps = ((int32_t)this->_number_of_microsteps * (int32_t)thousands_of_turn) / 1000;
  this->step((int16_t)steps);  
}

/***************************************************************
 * stepMotor()
 * advances motor one step
 * 
 * pin: microcontroller pin tied to STEP pin of A4988.     
 * 
 * Note from A4988 datasheet:
 * STEP minimum, HIGH pulse widtht 1μs
 * STEP minimum, LOW  pulse widtht 1μs
 ***************************************************************/
void dwStepperDriver::stepMotor()
{
  digitalWrite(this->_step_pin, HIGH);
  delayMicroseconds(PULSE_WIDTH);
  digitalWrite(this->_step_pin, LOW);
  delayMicroseconds(PULSE_WIDTH);
}

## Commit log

2020-04-14 updated License
    [2003-hall-sensors-board-platter.kicad_pcb]
2020-05-01 added 2003-hall-sensor
2020-05-27 modified STL
    [step-motor-spacer-01-01-FINAL.stl]
2020-11-11 add ir-barrier-01-01-FINAL.stl
    [ir-barrier-01-01-FINAL.stl]
2020-11-18 added bearing-holder-1-00-02-FINAL.stl
    [bearing-holder-1-00-02-FINAL.stl]
2020-11-18 added bearing01.png
2020-11-18 modified bearing-holder-platter-01-01-Final.stl
    [bearing-holder-platter-01-01-Final.stl]
2020-11-18 added bearing02.png
2020-11-24 added platter-01-01-FINAL.stl
    [platter-01-01-FINAL.stl]
2020-11-25 added base-piatto-01-01-FINAL.stl
    [base-piatto-01-01-FINAL.stl]
2021-01-30 add carousel-plate-2-01-01-FINAL.stl
    [carousel-plate-2-01-01-FINAL.stl]
2021-03-07 added Arduino test firmaware
2021-03-07 schematic in PDF
2021-03-07 added power-board.png
2021-03-07 added gerbers
    [power-board-B_Cu.gbr, power-board-B_Mask.gbr, power-board-B_SilkS.gbr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]

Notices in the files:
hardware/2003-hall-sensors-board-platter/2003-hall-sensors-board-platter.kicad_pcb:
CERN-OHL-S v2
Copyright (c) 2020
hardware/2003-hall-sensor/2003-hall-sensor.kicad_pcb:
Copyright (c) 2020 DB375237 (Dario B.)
